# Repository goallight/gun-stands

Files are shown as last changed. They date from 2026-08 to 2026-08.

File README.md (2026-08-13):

# gun-stands

Parametric 3D-printable pistol stands. Designs live in YAML, geometry lives in
Python, and the build spits out STLs plus a Bambu Studio project file with the
two-colour parts already assigned.

Two ways to make a stand:

- **refit** — take a stand model you already like and recut the magazine
  pockets to fit your mags. Everything outside the pockets stays untouched.
- **generate** — build a stand from measurements alone, no donor model.

```bash
pip install -r requirements.txt

python build.py specs/walther_pdp.yaml            # STLs + .3mf into builds/
python build.py specs/walther_pdp.yaml --fit-test  # clearance coupon
python build.py specs/glock19.yaml --lean-test     # grip angle coupon
python build.py specs/sig_p365x.yaml --preview     # build + top-down PNG
python build.py --all                                # everything in specs/
```

## The clearance workflow

This is the part worth being disciplined about. Pocket fit is the whole design.

1. Measure the magazine cross-section with calipers. Put it in `mag.width`
   (long dimension) and `mag.thickness` (short one).
2. `python build.py specs/yours.yaml --fit-test` and print the coupon.
   It carries one pocket per candidate clearance, at **full depth** and with
   the same wall thicknesses as the real stand.
3. Drop a mag in each pocket, pick the one you like, put that number in
   `mag.clearance`, and build the stand.

`clearance` is the **total** added to the pocket, split evenly between the two
sides. `0.25` means 0.125 mm per side. Reference points from the Walther PDP:

| Clearance | Feel |
|---|---|
| 0.25 | snug, very little play — what the PDP shipped with |
| 0.40 | drops in with light guidance |
| 0.60 | easy one-handed drop-in, slight wobble |

Print the coupon with the exact filament and profile you'll use for the stand.
A different spool or a flow tweak can eat 0.125 mm of clearance on its own.

## The grip angle workflow

The grip tower lean angle matters as much as pocket clearance. Every pistol
has a different grip angle, and guessing from spec sheets doesn't work — the
stand slot lean depends on how the gun actually rests, not just the number on
paper.

1. `python build.py specs/yours.yaml --lean-test` and print the coupon.
   It carries one slot per candidate angle (default 10, 13, 16, 19, 22
   degrees), each labeled on the back face.
2. Drop the grip into each slot and pick the angle where it sits flush with
   the most contact.
3. Put that number in `grip.lean` and build the stand.

`lean_test_angles` in the YAML controls which angles the coupon includes.

## Image logos

Logos can be either text strings or image files. Text logos use
`logo.text` and `logo.size` (cap height). Image logos use `logo.image`
(path to an image — PNG, JPEG, etc.) and `logo.size` (target width in mm).

Dark pixels become solid geometry; light pixels become background. The image
is traced into vector contours and extruded onto the deck as a separate colour
body, same as text logos.

Tips for image logos:
- Crop the image tight to the logo. Whitespace or small distant features
  (like a registered trademark symbol) stretch the bounding box and shrink
  the actual logo.
- For transparent PNGs, convert to a white background first, or the tracer
  may pick up gray from the alpha channel.

## Two-colour logos

`logo.letter_height` and `logo.banner_height` are how far the lettering stands
off the deck. They matter more than they look: over a dark base colour, four
layers of a light filament still lets black telegraph through. Five is a
minimum and eight is comfortable.

`printing.snap_logo_to_layers` rounds both heights to whole layers at your
`layer_height`, so 1.6 mm stays 8 layers instead of silently becoming 4.5 and
rounding down. A test enforces this.

Purge volume matters as much as height. Light-onto-dark is the worst-case
flush direction; under ~250 mm³ the first layers stay tinted no matter how
tall the feature is.

## Grip tower options

Generated stands build a grip tower from the `grip` measurements. Two extra
options control the layout:

- **`grip.align`** — `center` (default), `left`, or `right`. Shifts the tower
  to one side of the deck, leaving room for the logo beside it.
- **`grip.tower`** — path to an STL to use instead of generating a tower. The
  STL should be centred at X=0, Y=0 at the base, Z=0 centred. Use this to
  reuse a known-good tower shape across designs (e.g. the Walther tower works
  for the P365X).

## Slicer notes

`builds/<name>/<name>.3mf` opens in Bambu Studio or OrcaSlicer as **one object
with named parts**, filaments already assigned, oriented flat on the bed.

Generic 3MF exporters do not do this — Bambu reads them as plain geometry and
flattens every part into a single object. `standgen/export.py` writes Bambu's
own structure instead: one mesh object per part, an assembly object built from
components, and a `Metadata/model_settings.config` naming each part and its
extruder.

If you'd rather assemble by hand: load `<name>_stand.stl`, right-click the
object, **Add part → Load**, and pick the logo STL. They share an origin, so it
drops into place.

## Preview

`--preview` generates a top-down PNG alongside the STLs, showing the stand
layout with the logo highlighted. Useful for checking placement before
printing.

## Designs

| File | Mode | Notes |
|---|---|---|
| `specs/walther_pdp.yaml` | refit | Verified against a printed part. 0.25 mm clearance. Needs a donor (below). |
| `specs/sig_p365x.yaml` | generate | Verified. 0.25 mm clearance. Uses Walther donor grip tower. SIG brand mark logo. |
| `specs/glock19.yaml` | generate | Verified. 0.25 mm mag clearance, 16° lean. Glock logo. |
| `specs/sw_bodyguard_2.yaml` | generate | S&W Bodyguard 2.0 (.380 ACP). S&W logo. Verify clearance with coupon. |
| `specs/glock19_example.yaml` | generate | **Placeholder numbers.** Measure before printing. |

Adding a gun is a new YAML in `specs/`. Nothing else needs to change.

### Donor STLs are not in the repo

`donors/` is gitignored — donor models are third-party and usually can't be
redistributed. So a fresh clone can't build refit designs until you supply the
mesh yourself:

```
donors/PDP_Stand_V1.stl      <- drop your own copy here
```

Without it, `build.py` prints `skipped - donor STL not present` and moves on,
and the donor-dependent tests skip rather than fail. That keeps CI green on a
clone while still exercising the generator, the coupon builder, and every
design that doesn't need a donor. Generated designs are unaffected, and
`--fit-test` and `--lean-test` work for every design regardless, since coupons
are built from measurements alone.

## Repo layout

```
build.py               CLI
standgen/
  spec.py              YAML -> dataclasses, layer snapping
  primitives.py        boxes, chamfer cutters, ring nesting, solidity checks
  refit.py             pocket detection, pocket resizing, logo splitting
  pipeline.py          mode dispatcher (generate vs refit)
  generate.py          from-scratch stand (with lean + alignment support)
  fittest.py           clearance coupon
  leantest.py          grip angle coupon
  text.py              glyph outlines, banner rings, and image logo tracing
  export.py            STL + Bambu 3MF writer
specs/                 one YAML per gun
donors/                donor STLs for refit designs (gitignored)
logos/                 logo images for image-based logos
parts/                 derived geometry (e.g. extracted grip towers)
docs/                  design notes and session logs
tests/                 geometry regressions
```

## Tests

```bash
python -m pytest tests/ -q
```

They check the things that cost a failed print: pockets at the requested size,
walls parallel from floor to mouth, every part a watertight manifold with zero
bad edges, logo heights on layer boundaries, coupons at full depth, and a
refit never changing the donor's outside envelope.

CI runs the same suite on every push and uploads the built STLs and 3MFs as
artifacts, so a green run means printable files are one click away.

## Known rough edges

- Pocket detection assumes axis-aligned rectangular pockets with vertical
  walls. If it misses, list them explicitly under `refit.pockets`.
- Image logo tracing works best with clean, high-contrast images. Noisy or
  low-resolution images may produce ragged contours.

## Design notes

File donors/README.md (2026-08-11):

# Donor models

STLs used by `mode: refit` designs.

`PDP_Stand_V1.stl` is a third-party Walther PDP stand. It is here so the
`walther_pdp` design builds out of the box. **Check the original model's
licence before making this repository public** — many printable models are
non-commercial or no-derivatives, and redistributing the mesh may not be
allowed even though modifying it for your own use is.

If in doubt: delete the STL, add `donors/*.stl` to `.gitignore`, and keep the
design YAML. Anyone with their own copy of the donor can still build it.

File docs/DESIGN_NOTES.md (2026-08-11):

# Design notes

Everything learned building the Walther PDP stand, kept because most of it will
bite again on the next gun.

## Measured numbers

| | Value |
|---|---|
| Magazine cross-section | 31.75 × 20.45 mm |
| Donor pockets (as downloaded) | 33.00 × 22.40 mm — 1.25 / 1.95 mm of slop |
| Final pockets | 32.00 × 20.70 mm (0.25 total, 0.125 per side) |
| Pocket depth | 36 mm, floor at 4 mm, mouth at 40 mm |
| Lead-in chamfer | 1 mm at 45° |
| Deck plane | y = 6 |
| Letters | 1.6 mm proud (8 layers @ 0.2) |
| Banner ribbon | 2.0 mm proud (10 layers @ 0.2) |
| Envelope | 130 × 62.77 × 80 mm |
| Walls at 0.25 clearance | 4.50 mm ends, 12.50 mm between, 4.65 mm front/back |

## Clearance

Total, split evenly. Tested at full depth on a coupon printed with the same
filament and profile as the stand. 0.25 won; 0.40 was noticeably loose and 0.60
wobbled.

The coupon has to be **full depth**. A 12 mm test tells you nothing about
binding at 36 mm, and nothing about whether the mag bottoms out.

## Second-colour opacity

Feature height determines how many layers of the accent colour sit over the
base. Four is not enough over black — it telegraphs through. The original
design's 0.9 mm letters worked out to 4.5 layers at 0.2 mm, which rounds down
to 4.

Rule adopted: **5 layers minimum, 8 comfortable**, and heights snapped to whole
layers. `spec.py` does the snapping, `tests/test_build.py` enforces it.

Purge volume is the other half. Light-onto-dark is the worst-case flush
direction; below roughly 250 mm³ the first layers stay tinted regardless of
height.

## Boolean gotchas

**Seams from fill-then-cut.** Filling old pockets and cutting new ones leaves
the union seam exactly where the old wall was. When the new chamfer reaches
past that plane, the difference produces slivers — 2 non-manifold edges, and
0.008 mm apart, so they collapse on float32 STL export. Fix: oversize the fill
blocks (3 mm) so the seam lands inside existing material and disappears.

**float32 collapse.** Boolean output can carry vertices closer together than
float32 can resolve at these coordinates (~5 × 10⁻⁵ mm at x ≈ 400). Translating
to the origin does *not* fix it — the near-duplicates are real geometry, not
rounding. The fix is avoiding the sliver, not chasing precision.

**Prefer surgery to booleans** when the operation is topological rather than
geometric. Splitting the logo off the deck via boolean left 685 bad edges.
Deleting the raised faces and re-capping the holes with the exact existing
boundary vertices gave zero, and reused vertices merge cleanly.

## Ring nesting

Rings must be nested by **whole-polygon containment**, not by testing a fill
point. A ribbon is an outer ring plus an inner ring; the fill point of the
outer polygon also lands inside the inner one, so a point test makes each look
nested in the other and silently drops both. Cost an hour.

Depth parity does the rest: even depth is a shell, odd depth is a hole. That
keeps the counters in `A` and `R` open while stopping letters inside a banner
from being read as holes of the banner.

## Pocket detection

Slice horizontally, keep loops that are rectangles and are enclosed by another
loop in the same slice. One more filter is essential: a real pocket has
material on all four sides, so it never touches the model's own XZ footprint.
Without that, the magazine bar itself gets detected as a giant pocket.

## Bambu 3MF

A generic 3MF is not enough. Bambu reads it as plain geometry and flattens
every part into one object, so the parts and their filament assignments vanish.

What works — `standgen/export.py`:

- `3D/3dmodel.model` with one `<object>` per part, plus an assembly `<object>`
  whose `<components>` reference them
- `Metadata/model_settings.config` with a `<part>` per component, each carrying
  `name` and `extruder`
- `p:UUID` attributes and `requiredextensions="p"` on the root element
- Rotate Y-up model space to Z-up bed space and centre on the plate

Opens as one object with named parts and colours already assigned.

## Generator layout trap

The deck must butt against the back of the mag bar, not run underneath it. If
it runs underneath, the union fills the pockets up to deck height and the
pockets are quietly shallower than requested. Caught by
`test_pocket_walls_are_parallel_top_to_bottom`, not by eye.

## Checks worth keeping

Every part is verified watertight with zero non-manifold edges before it is
written. `bad_edges()` counts edges not shared by exactly two faces; a clean
solid gives 0. The refit path additionally asserts the donor's outside envelope
is unchanged — a refit should only ever touch the pockets.

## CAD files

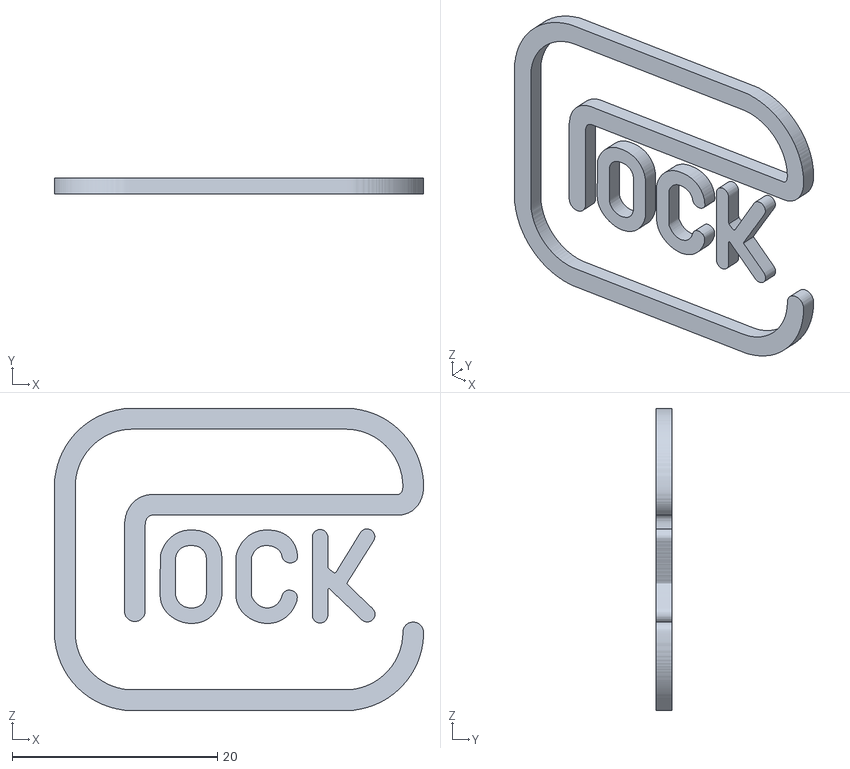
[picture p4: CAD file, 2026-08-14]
builds/glock19/glock19_letters.stl
36.0 x 1.60 x 29.5

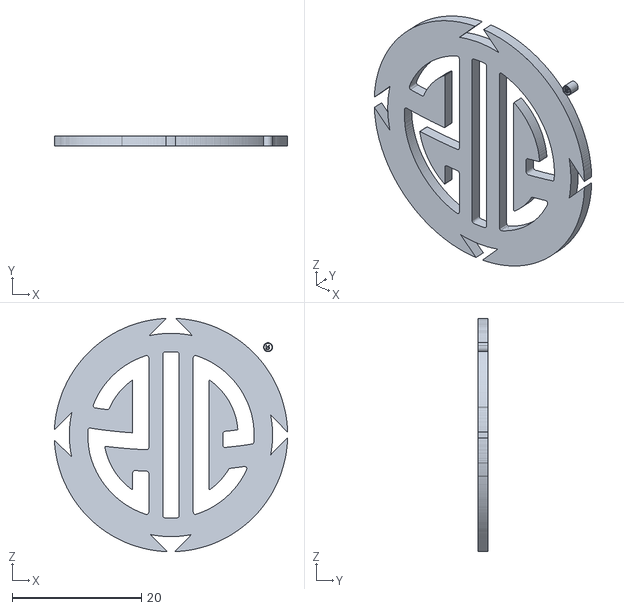
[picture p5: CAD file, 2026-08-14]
builds/sig_p365x/sig_p365x_letters.stl
36.0 x 1.60 x 36.0

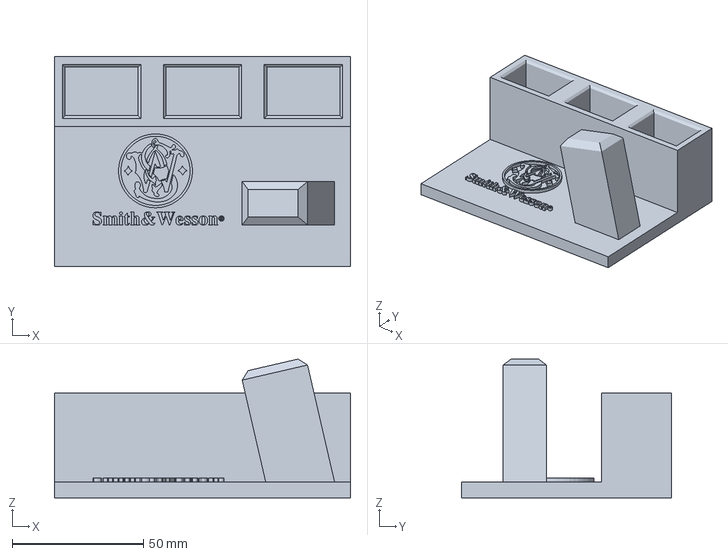
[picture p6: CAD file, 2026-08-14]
builds/sw_bodyguard_2/sw_bodyguard_2.3mf
112.7 x 80.0 x 52.9 mm

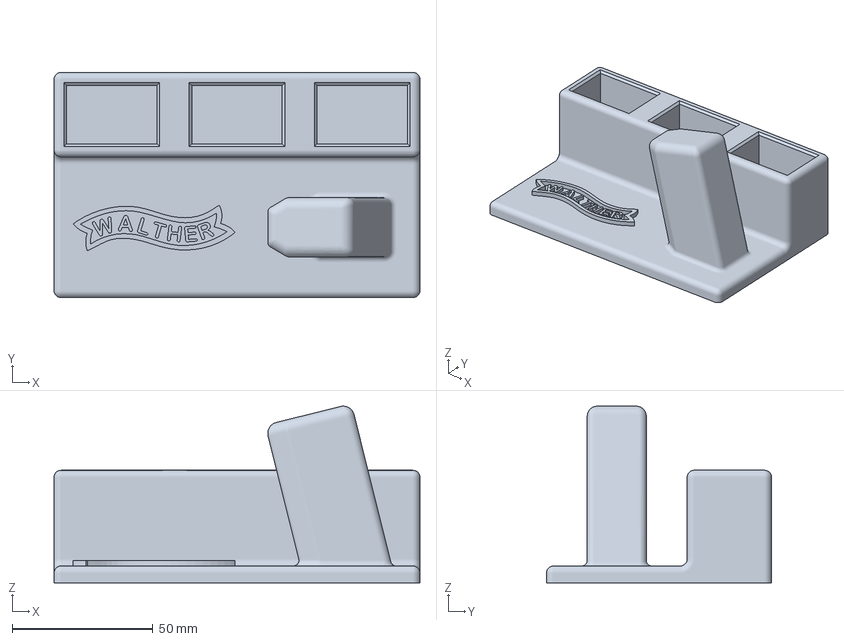
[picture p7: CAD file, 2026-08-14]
builds/walther_pdp/walther_pdp.3mf
130.0 x 80.0 x 62.8 mm

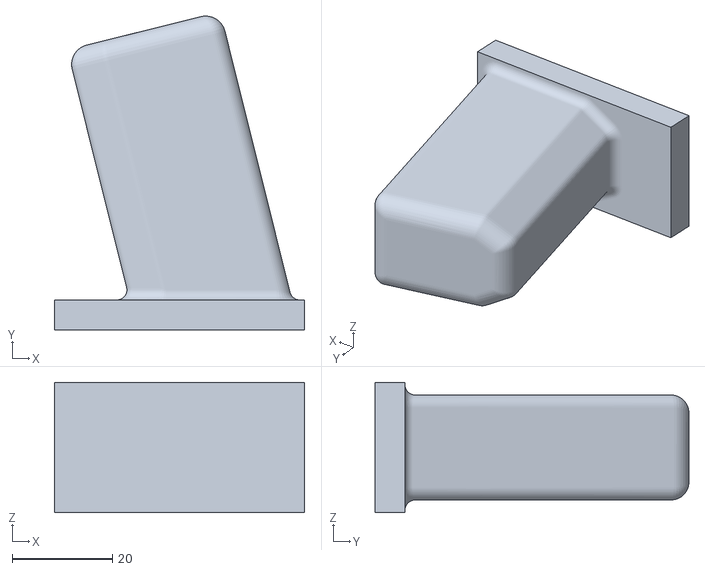
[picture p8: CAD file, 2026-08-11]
parts/grip_tower_walther.stl
50.0 x 62.8 x 26.0

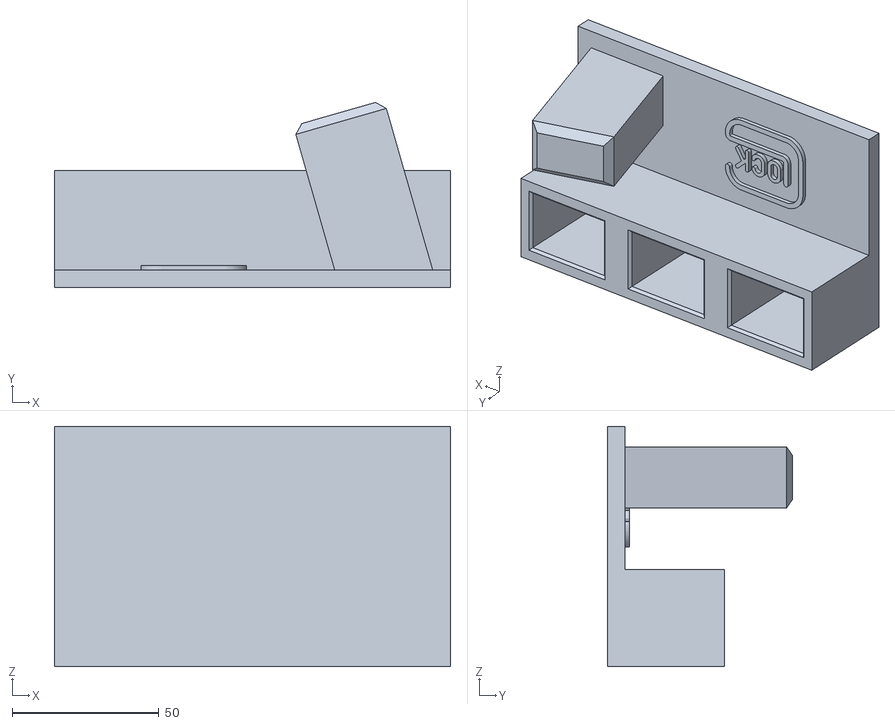
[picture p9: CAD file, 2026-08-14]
builds/glock19/glock19_single.stl
135.1 x 63.2 x 82.0

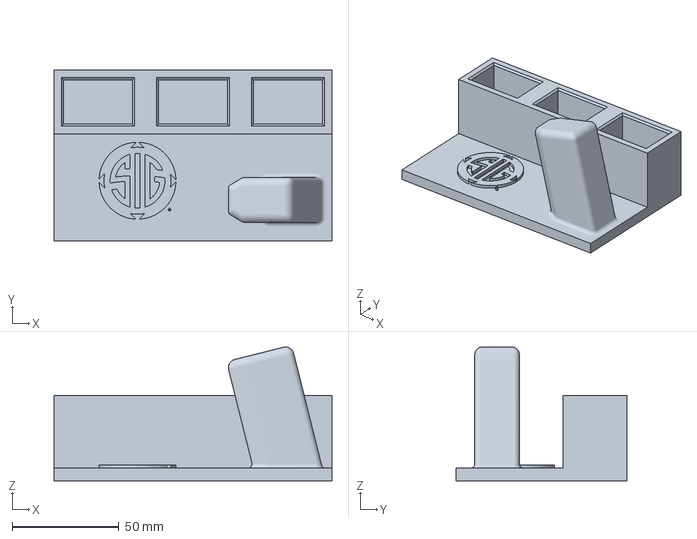
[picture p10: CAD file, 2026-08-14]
builds/sig_p365x/sig_p365x.3mf
130.3 x 80.0 x 62.8 mm

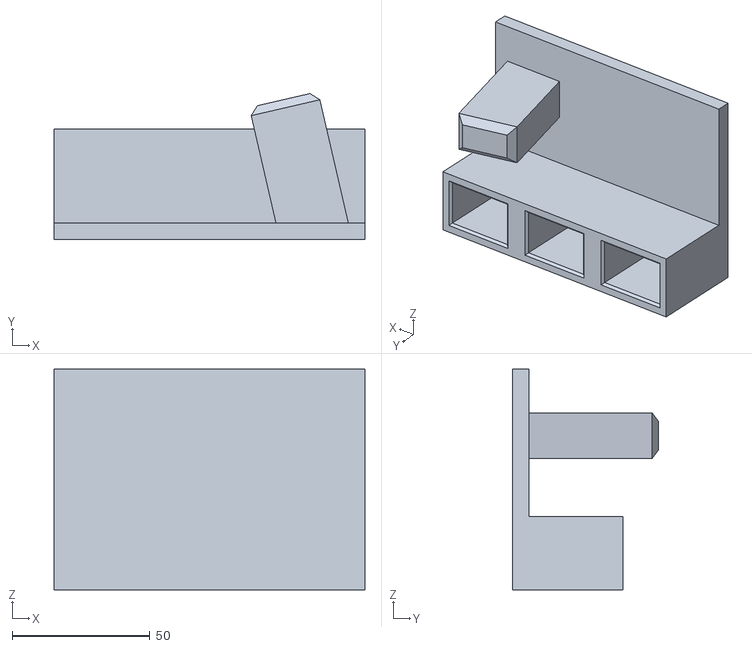
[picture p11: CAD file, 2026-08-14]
builds/sw_bodyguard_2/sw_bodyguard_2_stand.stl
112.7 x 52.9 x 80.0

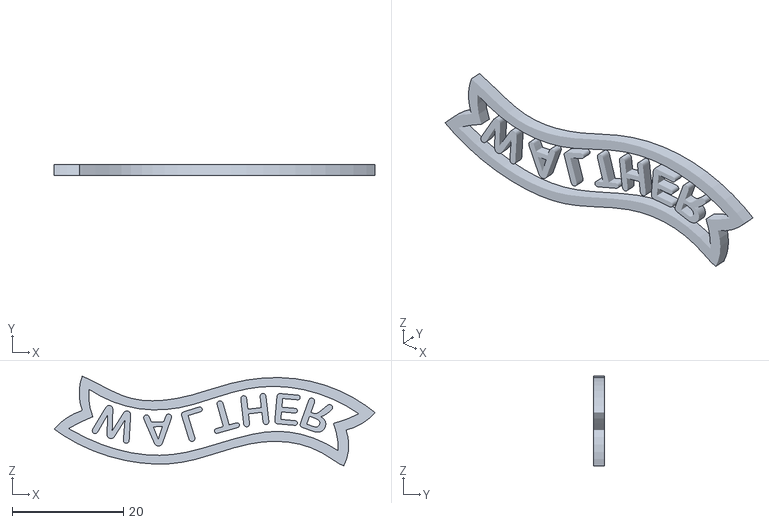
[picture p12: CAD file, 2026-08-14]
builds/walther_pdp/walther_pdp_logo.stl
57.6 x 2.00 x 16.1

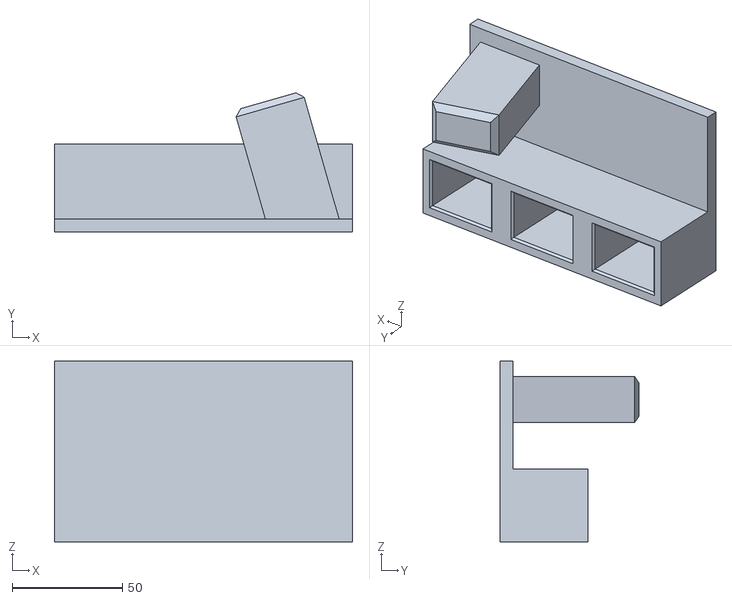
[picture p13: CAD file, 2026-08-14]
builds/glock19/glock19_stand.stl
135.1 x 63.2 x 82.0

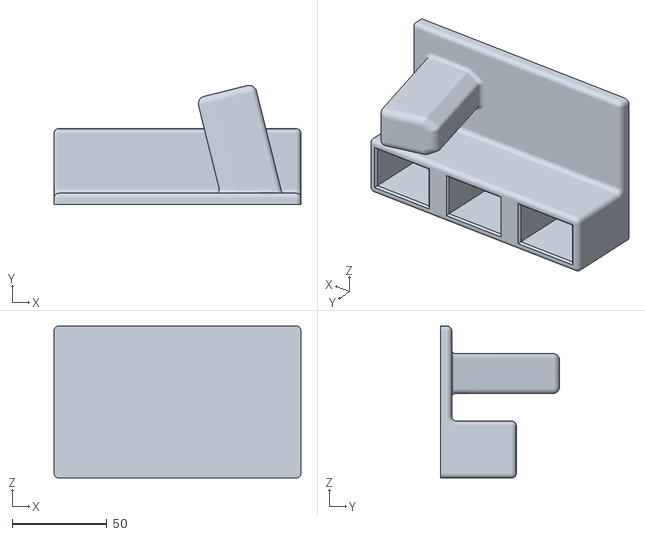
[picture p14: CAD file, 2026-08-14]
builds/walther_pdp/walther_pdp_stand.stl
130.0 x 62.8 x 80.0

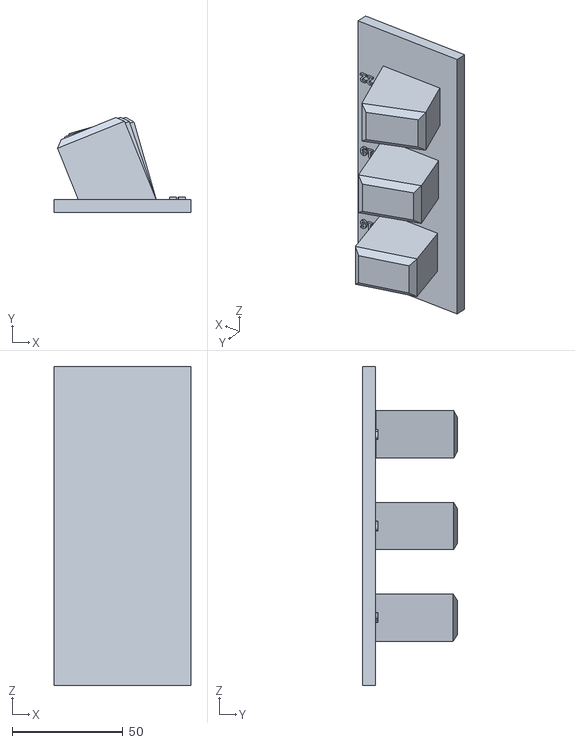
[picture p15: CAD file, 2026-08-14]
builds/glock19/glock19_lean_test.stl
61.8 x 43.1 x 144.2

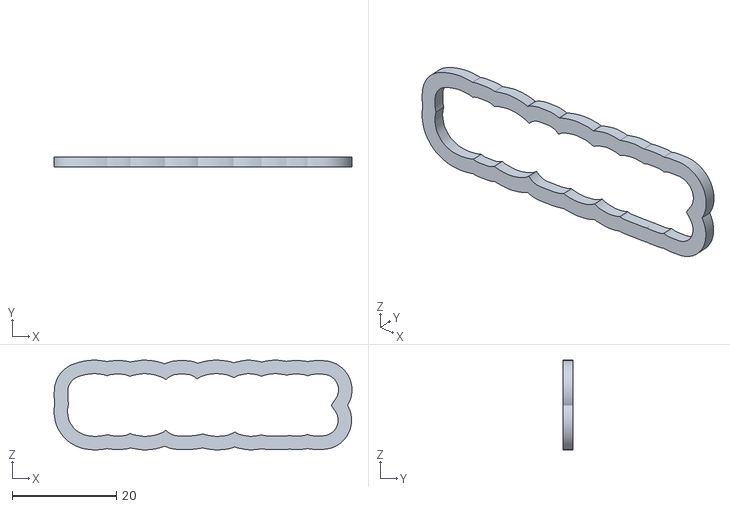
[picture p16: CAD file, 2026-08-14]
builds/sig_p365x/sig_p365x_banner.stl
57.3 x 2.00 x 17.2

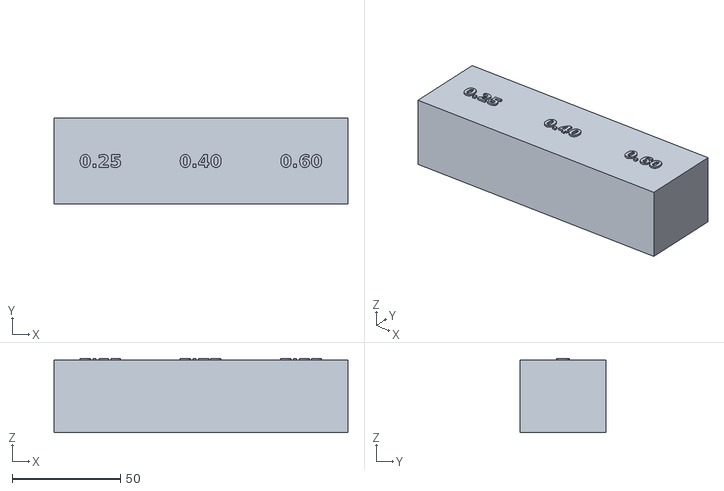
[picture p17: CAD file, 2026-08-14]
builds/glock19/glock19_fit_test.stl
136.0 x 40.0 x 34.4

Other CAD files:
builds/sig_p365x/sig_p365x_stand.stl
builds/sig_p365x/sig_p365x_single.stl
builds/walther_pdp/walther_pdp_single.stl
builds/glock19/glock19.3mf
builds/sig_p365x/sig_p365x_fit_test.stl

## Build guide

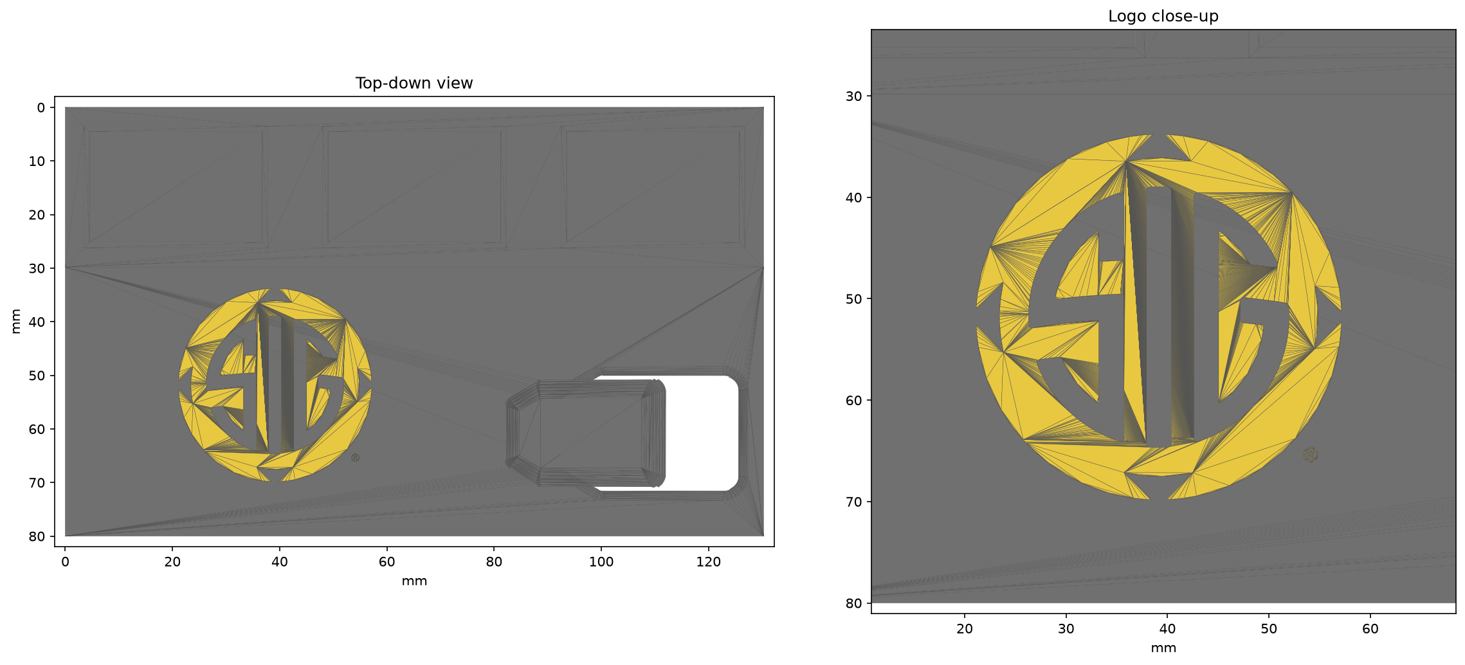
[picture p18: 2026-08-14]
builds/sig_p365x/sig_p365x_preview.png

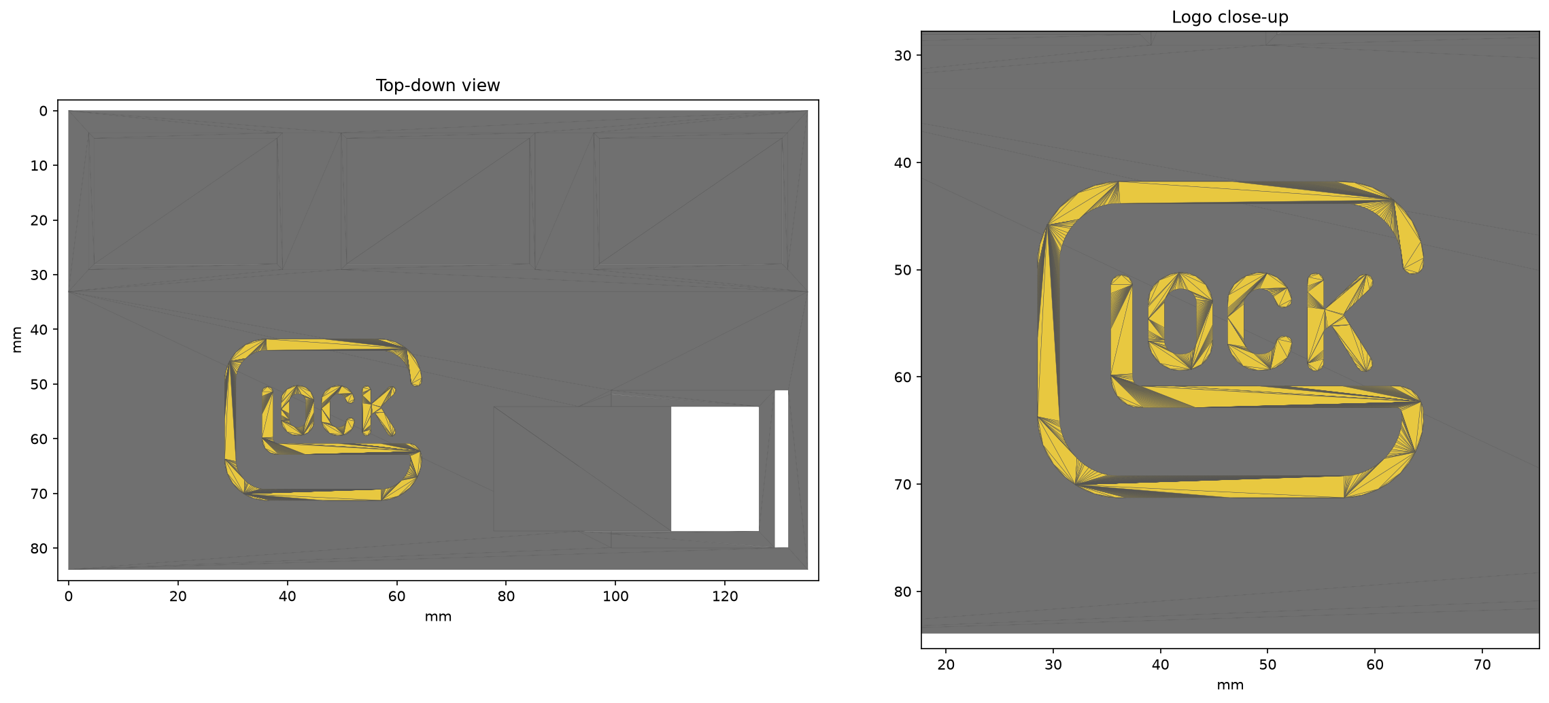
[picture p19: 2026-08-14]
builds/glock19/glock19_preview.png

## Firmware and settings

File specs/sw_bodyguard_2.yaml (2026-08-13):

# Smith & Wesson Bodyguard 2.0 (.380 ACP)
# Note: this is the Bodyguard 2.0, NOT the original Bodyguard
# Workflow: measure -> --fit-test -> print coupon -> set clearance
name: sw_bodyguard_2
mode: generate

mag:
  width: 27.70
  thickness: 18.35
  count: 3
  clearance: 0.15         # verified with fit-test coupon
  depth: 36.0
  floor: 4.0
  chamfer: 1.0

grip:
  width: 28.05
  thickness: 19.00
  clearance: 2.5
  height: 46.0
  lean: 13.0              # standard grip angle, same as SIG/Walther
  align: right

base:
  thickness: 6.0
  depth: 80.0
  gap: 18.0

logo:
  image: ../logos/SmithWesson-logo.jpg
  size: 50.0
  letter_height: 1.6
  banner: false

printing:
  layer_height: 0.2
  snap_logo_to_layers: true

fit_test_clearances: [0.10, 0.15, 0.20]
lean_test_angles: [10, 13, 16, 19, 22]

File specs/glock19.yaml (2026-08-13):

# Glock 19 - generated from measurements.
# Workflow: measure -> `--fit-test` -> print the coupon -> set `clearance`.
name: glock19
mode: generate

mag:
  width: 33.20
  thickness: 22.75
  count: 3
  clearance: 0.25         # verified with fit-test coupon
  depth: 36.0
  floor: 4.0
  chamfer: 1.0

grip:
  width: 34.65
  thickness: 23.40
  clearance: 2.5
  height: 56.0
  lean: 16.0              # verified with lean-test coupon
  wall: 4.0
  slot_depth: 50.0
  align: right

base:
  thickness: 6.0
  depth: 80.0
  gap: 18.0

logo:
  image: ../logos/glock-logo-cropped.png
  size: 36.0
  letter_height: 1.6
  banner: false

printing:
  layer_height: 0.2
  snap_logo_to_layers: true

fit_test_clearances: [0.25, 0.40, 0.60]
lean_test_angles: [16, 19, 22]

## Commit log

2026-08-11 SIG P365X stand: generated design with image logo and donor grip tower
    - Add SIG P365X design (generate mode, 0.25mm clearance verified)
    - Support PNG image logos traced to 3D geometry via contourpy
    - Support donor grip towers (reuse Walther tower for P365X)
    - Add grip.align option (left/center/right) for tower placement
    - Add --preview flag for top-down PNG renders
    - Handle missing donor STLs gracefully (skip instead of fail)
    - Tests skip cleanly when donor STLs are absent
    [grip_tower_walther.stl]
2026-08-12 Glock 19 stand + lean-test coupon for verifying grip angles
    - Add Glock 19 design with image logo (cropped to remove trademark symbol)
    - Add --lean-test coupon: slots at 10/13/16/19/22 degrees, labeled, same
    workflow as --fit-test so grip angle is verified by print, not guessed
    - Fix grip tower to lean the entire body, not just the slot cutter —
    the old tower was straight up and down regardless of lean setting
    - Update P365X lean to 13 degrees (measured from Walther donor tower)
    - lean_test_angles configurable per design in YAML
    [glock19.yaml, sig_p365x.yaml]
2026-08-12 Ignore entire donors/ directory and move derived tower to parts/
    donors/ contains third-party models that can't be redistributed.
    The extracted Walther grip tower is our own derived geometry, so it
    moves to parts/ where it's safe to track.
    [grip_tower_walther.stl]
2026-08-12 Rename designs/ to specs/ and out/ to builds/
    specs/ holds the YAML measurement specs, builds/ holds the printable
    STLs and 3MFs. Clearer naming for when the repo goes public.
2026-08-12 Fix lean-test coupon: arrange towers front-to-back, fit on 256mm bed
    Towers were side-by-side in X (the lean direction) making the coupon
    364mm wide. Now arranged front-to-back (Z) at 84x214mm. Labels
    embossed on the deck instead of rotated onto the side face.
    Also mark Glock 19 mag clearance as verified at 0.25mm.
    [glock19.yaml]
2026-08-12 Slim down lean-test coupon: 2mm walls, shorter towers for easy grip fitting
    Full 4mm walls were too thick to fit inside the grip for testing.
    Lean test only needs to check the angle, not be structural. Walls
    thinned to 2mm, towers shortened to 35mm, foot reduced.
    66x184mm footprint fits easily on a 256mm bed.
2026-08-12 Blade-style grip tower: tower replicates a magazine, grip slides over it
    The grip tower is now a solid blade sized to the inside grip dimensions
    (magazine well) minus clearance, replacing the slotted shell design.
    Lean test coupon updated to match.
2026-08-12 Use extra clearance on lean test blades for easy slide-on testing
    Lean test is about angle not fitment, so blades use at least 1.5mm
    clearance (0.75mm per side) for easy on/off.
2026-08-12 Remove protruding foot from lean test blades — flush with base plate
2026-08-13 Lean test v2: tighter blades (2mm clearance), Glock narrowed to 16/19/22
    [glock19.yaml]
2026-08-13 Glock 19: set lean to 16° (verified), bump lean test clearance to 2.5mm
    Lean angle confirmed via printed coupon. Also fixed lean_test_angles
    not being loaded from YAML specs.
    [glock19.yaml]
2026-08-13 Remove protruding foot from grip tower — blade sits flush on deck
2026-08-13 Glock 19: bump grip clearance to 2.5mm for proper magwell fit
    [glock19.yaml]
2026-08-13 Fix gap between leaned blade and deck — extend blade down and clip at deck surface
2026-08-13 Clean up docs, remove orphaned files, fix README accuracy
    - Add sw_bodyguard_2 to Designs table, update glock19 as verified
    - Add pipeline.py and docs/ to repo layout
    - Say "image" not "PNG" since JPEG works too
    - Remove orphaned glock-logo-png_seeklogo-61407.png
    - Add SmithWesson-logo.jpg to tracked logos
    [sw_bodyguard_2.yaml]
2026-08-13 S&W Bodyguard 2.0: set mag clearance to 0.15mm (verified with coupon)
    [sw_bodyguard_2.yaml]
2026-08-14 Track builds/ directory so users can download pre-built STLs
    [glock19.3mf, glock19_fit_test.stl, glock19_lean_test.stl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]
